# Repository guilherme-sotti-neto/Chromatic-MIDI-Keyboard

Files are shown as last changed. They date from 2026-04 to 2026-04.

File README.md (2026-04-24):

# Chromatic MIDI Button Keyboard 

# About 
This project was made to be open for anyone who wants to make their own Chromatic MIDI Keyboard at home. 
I tried to make it as reliable and fixable as possible.

# Components 
- 1 Arduino Leonardo
- 3 1/4W 220 ohm Resistor
- 3 Buttons 
- 51 Diodes 1N4148 (I recommend them because they are very cheap and overkill for this project)
- 99 MX Hotswap Sockets
- 99 MX 5 Pins Silver Mechanical Switches

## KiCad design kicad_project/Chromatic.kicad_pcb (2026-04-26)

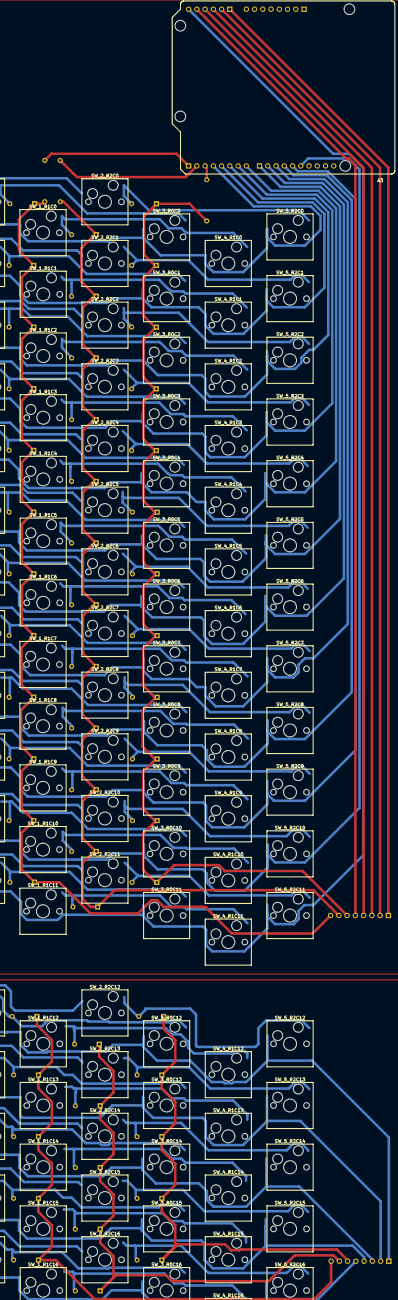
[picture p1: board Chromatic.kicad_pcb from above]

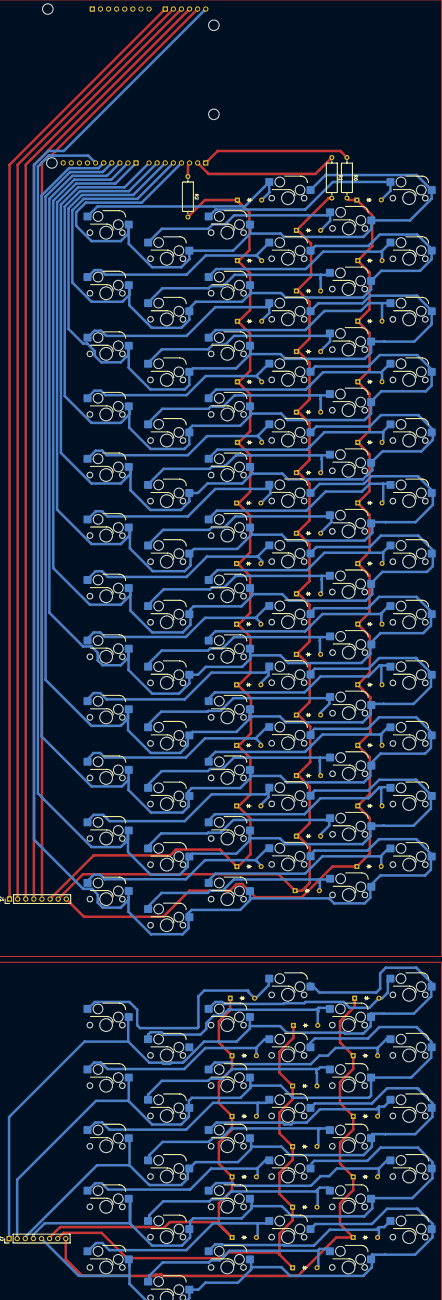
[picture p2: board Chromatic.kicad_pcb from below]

Board: 2 copper layers, 159 parts (56 on the bottom side), 82 nets.

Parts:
A3: Arduino_Leonardo_Shield; ARDUINO_A000066
D_R0C0, D_R0C1, D_R0C2, D_R0C3, D_R0C4, D_R0C5, D_R0C6, D_R0C7, D_R0C8, D_R0C9, D_R0C10, D_R0C11, D_R0C12, D_R0C13, D_R0C14, D_R0C15, D_R0C16, D_R1C0, D_R1C1, D_R1C2, D_R1C3, D_R1C4, D_R1C5, D_R1C6, D_R1C7, D_R1C8, D_R1C9, D_R1C10, D_R1C11, D_R1C12, D_R1C13, D_R1C14, D_R1C15, D_R1C16, D_R2C0, D_R2C1, D_R2C2, D_R2C3, D_R2C4, D_R2C5, D_R2C6, D_R2C7, D_R2C8, D_R2C9, D_R2C10, D_R2C11, D_R2C12, D_R2C13, D_R2C14, D_R2C15, D_R2C16: Diode_DO-35
J1: J1; PinHeader_1x08_P2.54mm_Vertical
J2: J2; PinHeader_1x08_P2.54mm_Vertical
R0, R1, R2: Resistor; R_Axial_DIN0309_L9.0mm_D3.2mm_P12.70mm_Horizontal
SW_0_R0C0, SW_0_R0C1, SW_0_R0C2, SW_0_R0C3, SW_0_R0C4, SW_0_R0C5, SW_0_R0C6, SW_0_R0C7, SW_0_R0C8, SW_0_R0C9, SW_0_R0C10, SW_0_R0C11, SW_0_R0C12, SW_0_R0C13, SW_0_R0C14, SW_0_R0C15, SW_0_R0C16, SW_1_R1C0, SW_1_R1C1, SW_1_R1C2, SW_1_R1C3, SW_1_R1C4, SW_1_R1C5, SW_1_R1C6, SW_1_R1C7, SW_1_R1C8, SW_1_R1C9, SW_1_R1C10, SW_1_R1C11, SW_1_R1C12, SW_1_R1C13, SW_1_R1C14, SW_1_R1C15, SW_1_R1C16, SW_2_R2C0, SW_2_R2C1, SW_2_R2C2, SW_2_R2C3, SW_2_R2C4, SW_2_R2C5, SW_2_R2C6, SW_2_R2C7, SW_2_R2C8, SW_2_R2C9, SW_2_R2C10, SW_2_R2C11, SW_2_R2C12, SW_2_R2C13, SW_2_R2C14, SW_2_R2C15, SW_2_R2C16, SW_3_R0C0, SW_3_R0C1, SW_3_R0C2, SW_3_R0C3, SW_3_R0C4, SW_3_R0C5, SW_3_R0C6, SW_3_R0C7, SW_3_R0C8, SW_3_R0C9, SW_3_R0C10, SW_3_R0C11, SW_3_R0C12, SW_3_R0C13, SW_3_R0C14, SW_3_R0C15, SW_3_R0C16, SW_4_R1C0, SW_4_R1C1, SW_4_R1C2, SW_4_R1C3, SW_4_R1C4, SW_4_R1C5, SW_4_R1C6, SW_4_R1C7, SW_4_R1C8, SW_4_R1C9, SW_4_R1C10, SW_4_R1C11, SW_4_R1C12, SW_4_R1C13, SW_4_R1C14, SW_4_R1C15, SW_4_R1C16, SW_5_R2C0, SW_5_R2C1, SW_5_R2C2, SW_5_R2C3, SW_5_R2C4, SW_5_R2C5, SW_5_R2C6, SW_5_R2C7, SW_5_R2C8, SW_5_R2C9, SW_5_R2C10, SW_5_R2C11, SW_5_R2C12, SW_5_R2C13, SW_5_R2C14, SW_5_R2C15, SW_5_R2C16: Keyswitch; Hotswap_MX_1.00u

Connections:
Column 0: A3.D3 (D3_INT0), SW_0_R0C0.1, SW_1_R1C0.1, SW_2_R2C0.1, SW_3_R0C0.1, SW_4_R1C0.1, SW_5_R2C0.1
Column 1: A3.D4, SW_0_R0C1.1, SW_1_R1C1.1, SW_2_R2C1.1, SW_3_R0C1.1, SW_4_R1C1.1, SW_5_R2C1.1
Column 2: A3.D5, SW_0_R0C2.1, SW_1_R1C2.1, SW_2_R2C2.1, SW_3_R0C2.1, SW_4_R1C2.1, SW_5_R2C2.1
Column 3: A3.D6, SW_0_R0C3.1, SW_1_R1C3.1, SW_2_R2C3.1, SW_3_R0C3.1, SW_4_R1C3.1, SW_5_R2C3.1
Column 4: A3.D7 (D7_INT4), SW_0_R0C4.1, SW_1_R1C4.1, SW_2_R2C4.1, SW_3_R0C4.1, SW_4_R1C4.1, SW_5_R2C4.1
Column 5: A3.D8, SW_0_R0C5.1, SW_1_R1C5.1, SW_2_R2C5.1, SW_3_R0C5.1, SW_4_R1C5.1, SW_5_R2C5.1
Column 6: A3.D9, SW_0_R0C6.1, SW_1_R1C6.1, SW_2_R2C6.1, SW_3_R0C6.1, SW_4_R1C6.1, SW_5_R2C6.1
Column 7: A3.D10, SW_0_R0C7.1, SW_1_R1C7.1, SW_2_R2C7.1, SW_3_R0C7.1, SW_4_R1C7.1, SW_5_R2C7.1
Column 8: A3.D11, SW_0_R0C8.1, SW_1_R1C8.1, SW_2_R2C8.1, SW_3_R0C8.1, SW_4_R1C8.1, SW_5_R2C8.1
Column 9: A3.D12, SW_0_R0C9.1, SW_1_R1C9.1, SW_2_R2C9.1, SW_3_R0C9.1, SW_4_R1C9.1, SW_5_R2C9.1
Column 10: A3.D13, SW_0_R0C10.1, SW_1_R1C10.1, SW_2_R2C10.1, SW_3_R0C10.1, SW_4_R1C10.1, SW_5_R2C10.1
Column 11: A3.A5, SW_0_R0C11.1, SW_1_R1C11.1, SW_2_R2C11.1, SW_3_R0C11.1, SW_4_R1C11.1, SW_5_R2C11.1
Column 12: A3.A0, J1.1
Column 13: A3.A1, J1.2
Column 14: A3.A2, J1.3
Column 15: A3.A3, J1.4
Column 16: A3.A4, J1.5
D_R0C11: D_R0C0.1 (K), D_R0C1.1 (K), D_R0C2.1 (K), D_R0C3.1 (K), D_R0C4.1 (K), D_R0C5.1 (K), D_R0C6.1 (K), D_R0C7.1 (K), D_R0C8.1 (K), D_R0C9.1 (K), D_R0C10.1 (K), D_R0C11.1 (K), J1.8, R0.2
D_R1C11: D_R1C0.1 (K), D_R1C1.1 (K), D_R1C2.1 (K), D_R1C3.1 (K), D_R1C4.1 (K), D_R1C5.1 (K), D_R1C6.1 (K), D_R1C7.1 (K), D_R1C8.1 (K), D_R1C9.1 (K), D_R1C10.1 (K), D_R1C11.1 (K), J1.7, R1.2
D_R2C11: D_R2C0.1 (K), D_R2C1.1 (K), D_R2C2.1 (K), D_R2C3.1 (K), D_R2C4.1 (K), D_R2C5.1 (K), D_R2C6.1 (K), D_R2C7.1 (K), D_R2C8.1 (K), D_R2C9.1 (K), D_R2C10.1 (K), D_R2C11.1 (K), J1.6, R2.2
unnamed: D_R0C0.2 (A), SW_0_R0C0.2, SW_3_R0C0.2
unnamed: D_R0C1.2 (A), SW_0_R0C1.2, SW_3_R0C1.2
unnamed: D_R0C2.2 (A), SW_0_R0C2.2, SW_3_R0C2.2
unnamed: D_R0C3.2 (A), SW_0_R0C3.2, SW_3_R0C3.2
unnamed: D_R0C4.2 (A), SW_0_R0C4.2, SW_3_R0C4.2
unnamed: D_R0C5.2 (A), SW_0_R0C5.2, SW_3_R0C5.2
unnamed: D_R0C6.2 (A), SW_0_R0C6.2, SW_3_R0C6.2
unnamed: D_R0C7.2 (A), SW_0_R0C7.2, SW_3_R0C7.2
unnamed: D_R0C8.2 (A), SW_0_R0C8.2, SW_3_R0C8.2
unnamed: D_R0C9.2 (A), SW_0_R0C9.2, SW_3_R0C9.2
unnamed: D_R0C10.2 (A), SW_0_R0C10.2, SW_3_R0C10.2
unnamed: D_R0C11.2 (A), SW_0_R0C11.2, SW_3_R0C11.2
unnamed: D_R0C12.2 (A), SW_0_R0C12.2, SW_3_R0C12.2
unnamed: D_R0C12.1 (K), D_R0C13.1 (K), D_R0C14.1 (K), D_R0C15.1 (K), D_R0C16.1 (K), J2.8
unnamed: D_R0C13.2 (A), SW_0_R0C13.2, SW_3_R0C13.2
unnamed: D_R0C14.2 (A), SW_0_R0C14.2, SW_3_R0C14.2
unnamed: D_R0C15.2 (A), SW_0_R0C15.2, SW_3_R0C15.2
unnamed: D_R0C16.2 (A), SW_0_R0C16.2, SW_3_R0C16.2
unnamed: D_R1C0.2 (A), SW_1_R1C0.2, SW_4_R1C0.2
unnamed: D_R1C1.2 (A), SW_1_R1C1.2, SW_4_R1C1.2
unnamed: D_R1C2.2 (A), SW_1_R1C2.2, SW_4_R1C2.2
unnamed: D_R1C3.2 (A), SW_1_R1C3.2, SW_4_R1C3.2
unnamed: D_R1C4.2 (A), SW_1_R1C4.2, SW_4_R1C4.2
unnamed: D_R1C5.2 (A), SW_1_R1C5.2, SW_4_R1C5.2
unnamed: D_R1C6.2 (A), SW_1_R1C6.2, SW_4_R1C6.2
unnamed: D_R1C7.2 (A), SW_1_R1C7.2, SW_4_R1C7.2
unnamed: D_R1C8.2 (A), SW_1_R1C8.2, SW_4_R1C8.2
unnamed: D_R1C9.2 (A), SW_1_R1C9.2, SW_4_R1C9.2
unnamed: D_R1C10.2 (A), SW_1_R1C10.2, SW_4_R1C10.2
unnamed: D_R1C11.2 (A), SW_1_R1C11.2, SW_4_R1C11.2
unnamed: D_R1C12.2 (A), SW_1_R1C12.2, SW_4_R1C12.2
unnamed: D_R1C12.1 (K), D_R1C13.1 (K), D_R1C14.1 (K), D_R1C15.1 (K), D_R1C16.1 (K), J2.7
unnamed: D_R1C13.2 (A), SW_1_R1C13.2, SW_4_R1C13.2
unnamed: D_R1C14.2 (A), SW_1_R1C14.2, SW_4_R1C14.2
unnamed: D_R1C15.2 (A), SW_1_R1C15.2, SW_4_R1C15.2
unnamed: D_R1C16.2 (A), SW_1_R1C16.2, SW_4_R1C16.2
unnamed: D_R2C0.2 (A), SW_2_R2C0.2, SW_5_R2C0.2
unnamed: D_R2C1.2 (A), SW_2_R2C1.2, SW_5_R2C1.2
unnamed: D_R2C2.2 (A), SW_2_R2C2.2, SW_5_R2C2.2
unnamed: D_R2C3.2 (A), SW_2_R2C3.2, SW_5_R2C3.2
unnamed: D_R2C4.2 (A), SW_2_R2C4.2, SW_5_R2C4.2
unnamed: D_R2C5.2 (A), SW_2_R2C5.2, SW_5_R2C5.2
unnamed: D_R2C6.2 (A), SW_2_R2C6.2, SW_5_R2C6.2
unnamed: D_R2C7.2 (A), SW_2_R2C7.2, SW_5_R2C7.2
unnamed: D_R2C8.2 (A), SW_2_R2C8.2, SW_5_R2C8.2
unnamed: D_R2C9.2 (A), SW_2_R2C9.2, SW_5_R2C9.2
unnamed: D_R2C10.2 (A), SW_2_R2C10.2, SW_5_R2C10.2
unnamed: D_R2C11.2 (A), SW_2_R2C11.2, SW_5_R2C11.2
unnamed: D_R2C12.2 (A), SW_2_R2C12.2, SW_5_R2C12.2
unnamed: D_R2C12.1 (K), D_R2C13.1 (K), D_R2C14.1 (K), D_R2C15.1 (K), D_R2C16.1 (K), J2.6
unnamed: D_R2C13.2 (A), SW_2_R2C13.2, SW_5_R2C13.2
unnamed: D_R2C14.2 (A), SW_2_R2C14.2, SW_5_R2C14.2
unnamed: D_R2C15.2 (A), SW_2_R2C15.2, SW_5_R2C15.2
unnamed: D_R2C16.2 (A), SW_2_R2C16.2, SW_5_R2C16.2
unnamed: J2.1, SW_0_R0C12.1, SW_1_R1C12.1, SW_2_R2C12.1, SW_3_R0C12.1, SW_4_R1C12.1, SW_5_R2C12.1
unnamed: J2.2, SW_0_R0C13.1, SW_1_R1C13.1, SW_2_R2C13.1, SW_3_R0C13.1, SW_4_R1C13.1, SW_5_R2C13.1
unnamed: J2.3, SW_0_R0C14.1, SW_1_R1C14.1, SW_2_R2C14.1, SW_3_R0C14.1, SW_4_R1C14.1, SW_5_R2C14.1
unnamed: J2.4, SW_0_R0C15.1, SW_1_R1C15.1, SW_2_R2C15.1, SW_3_R0C15.1, SW_4_R1C15.1, SW_5_R2C15.1
unnamed: J2.5, SW_0_R0C16.1, SW_1_R1C16.1, SW_2_R2C16.1, SW_3_R0C16.1, SW_4_R1C16.1, SW_5_R2C16.1
Row 0: A3.D0 (D0/RX), R0.1
Row 1: A3.D1 (D1/TX), R1.1
Row 2: A3.D2 (D2_INT1), R2.1

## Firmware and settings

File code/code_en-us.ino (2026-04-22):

// Includes the native Arduino library for MIDI communication via USB cable.
// The computer will recognize the board as a musical instrument ("Arduino Leonardo:Arduino Leonardo MIDI 1 20:0").
#include "MIDIUSB.h"

// ==========================================
// PHYSICAL MATRIX CONFIGURATIONS
// ==========================================

// Defines the number of rows and columns in the button matrix.
const int NUM_ROWS = 3;  // 3 electrical rows.
const int NUM_COLS = 17; // 17 electrical columns.

// Calculates the maximum number of buttons the matrix supports (3 rows * 17 columns = 51 keys).
const int NUM_KEYS = 51; 

// Indicates which Arduino pins are connected to the Rows.
// Digital pins 0, 1, and 2.
int rowPins[NUM_ROWS] = {0, 1, 2}; 

// Indicates which Arduino pins are connected to the Columns.
// Digital pins 3 to 13, and analog pins A0 to A5 (used as digital).
int colPins[NUM_COLS] = {3, 4, 5, 6, 7, 8, 9, 10, 11, 12, 13, A0, A1, A2, A3, A4, A5};

// ==========================================
// STATE VARIABLES AND ANTI-NOISE FILTER (DEBOUNCE)
// ==========================================

// Array (list) that stores the CURRENT state of each key (true = pressed, false = released).
bool keyState[NUM_KEYS];

// Array that stores the LAST read state of each key to compare if there was a change.
bool lastKeyState[NUM_KEYS];

// Array that records the exact millisecond each key last changed state.
unsigned long lastDebounceTime[NUM_KEYS];

// Time in milliseconds that the Arduino must wait to confirm the button was actually
// pressed or released. This prevents the button's internal metallic "bounce" from generating double notes.
unsigned long debounceDelay = 10; 

// ==========================================
// CONTROL VARIABLES (OCTAVES AND SYSTEMS)
// ==========================================

// Stores the current octave shift. Starts at 0. Can go to +12 (high) or -12 (low).
int octaveShift = 0;      

// Defines which note system is active. 
// false = C-System (Initial default), true = B-System.
bool isBSystem = false;   

// Smart memory: Records the exact note sent to the computer when the key was pressed.
// This prevents a note from getting "stuck" playing forever if you change the octave before releasing it.
int notasAtivas[NUM_KEYS];

// Defines the "position" (mathematical index) of the control buttons within the matrix.
// These buttons are all in Column 0, but on different rows.
const int BTN_OCTAVE_DOWN = 0;  // Octave down button (Row 0 * 17 columns + Column 0)
const int BTN_OCTAVE_UP   = 17; // Octave up button (Row 1 * 17 columns + Column 0)
const int BTN_SYSTEM      = 34; // C/B switch button (Row 2 * 17 columns + Column 0)

// ==========================================
// NOTE MAPS (LOOK-UP TABLES)
// ==========================================

// MAP 1: C-SYSTEM (C-Griff) 
// Defines which default MIDI note each button will play. The number 0 indicates a button without a note (like functions).
int noteMapCSystem[NUM_KEYS] = {
  // Row 0 (The first '0' is the BTN_OCTAVE_DOWN button)
  0, 48, 51, 54, 57, 60, 63, 66, 69, 72, 75, 78, 81, 84, 87, 90, 93,
  // Row 1 (The first '0' is the BTN_OCTAVE_UP button)
  0, 49, 52, 55, 58, 61, 64, 67, 70, 73, 76, 79, 82, 85, 88, 91, 94,
  // Row 2 (The first '0' is the BTN_SYSTEM button)
  0, 50, 53, 56, 59, 62, 65, 68, 71, 74, 77, 80, 83, 86, 89, 92, 95
};

// MAP 2: B-SYSTEM (B-Griff)
// Alternative map for when the system switch button is activated.
int noteMapBSystem[NUM_KEYS] = {
  // Row 0
  0, 47, 50, 53, 56, 59, 62, 65, 68, 71, 74, 77, 80, 83, 86, 89, 92,
  // Row 1
  0, 48, 51, 54, 57, 60, 63, 66, 69, 72, 75, 78, 81, 84, 87, 90, 93,
  // Row 2
  0, 49, 52, 55, 58, 61, 64, 67, 70, 73, 76, 79, 82, 85, 88, 91, 94
};

// ==========================================
// SETUP: INITIAL PREPARATION (Runs only once)
// ==========================================
void setup() {
  // Configures all ROW pins to send power (OUTPUT).
  for (int i = 0; i < NUM_ROWS; i++) {
    pinMode(rowPins[i], OUTPUT);
    digitalWrite(rowPins[i], HIGH); // Keep HIGH (5V) so they remain inactive by default.
  }
  
  // Configures all COLUMN pins to receive power.
  // INPUT_PULLUP enables an internal resistor that keeps columns reading 5V (HIGH) when released.
  for (int i = 0; i < NUM_COLS; i++) {
    pinMode(colPins[i], INPUT_PULLUP);
  }
  
  // Clears all keyboard memories and timers to start fresh.
  for (int i = 0; i < NUM_KEYS; i++) {
    keyState[i] = false;
    lastKeyState[i] = false;
    lastDebounceTime[i] = 0;
    notasAtivas[i] = 0; 
  }
}

// ==========================================
// MAIN LOOP (Runs infinitely and as fast as possible)
// ==========================================
void loop() {
  // Calls the function that scans (radars) the keys.
  scanMatrix();
}

// ==========================================
// MATRIX SCANNING FUNCTION
// ==========================================
void scanMatrix() {
  // Loops through each of the 3 rows, one at a time.
  for (int r = 0; r < NUM_ROWS; r++) {
    
    // Activates the current row by dropping its voltage to 0V (LOW).
    digitalWrite(rowPins[r], LOW); 

    // While the row is active (0V), loops through each of the 17 columns checking for contact.
    for (int c = 0; c < NUM_COLS; c++) {
      
      // Calculates the unique identification number for the key (from 0 to 50).
      int keyIndex = r * NUM_COLS + c;

      // Reads the current column. The "!" symbol inverts the reading. 
      // Since pressing the key generates 0V (false), the "!" turns it into "true" for the code.
      bool reading = !digitalRead(colPins[c]); 

      // If the reading is different from the last recorded state (sign that someone touched or released):
      if (reading != lastKeyState[keyIndex]) {
        // Resets the timer for this specific key by recording the current time (millis).
        lastDebounceTime[keyIndex] = millis();
      }

      // Checks if the signal has stabilized longer than the debounceDelay (10ms).
      if ((millis() - lastDebounceTime[keyIndex]) > debounceDelay) {
        
        // If the stable reading is actually different from the official state saved in memory:
        if (reading != keyState[keyIndex]) {
          // Updates the official memory with the new state.
          keyState[keyIndex] = reading;

          // ==========================================
          // LOGIC FOR WHEN THE KEY IS PRESSED
          // ==========================================
          if (keyState[keyIndex]) {
            
            // --- 1. CHECK IF IT IS ONE OF THE FUNCTION BUTTONS ---
            if (keyIndex == BTN_OCTAVE_DOWN || keyIndex == BTN_OCTAVE_UP || keyIndex == BTN_SYSTEM) {
              
              if (keyIndex == BTN_OCTAVE_DOWN) {
                // Decreases 12 semitones with each press. 
                // Limit of -36 (3 octaves) so the user doesn't "get lost" in silence.
                octaveShift -= 12;
                if (octaveShift < -36) octaveShift = -36; 
              } 
              else if (keyIndex == BTN_OCTAVE_UP) {
                // Increases 12 semitones with each press.
                // Limit of 24 (2 octaves)
                octaveShift += 12;
                if (octaveShift > 24) octaveShift = 24;
              } 
              else if (keyIndex == BTN_SYSTEM) {
                // Toggles between C-System and B-System
                isBSystem = !isBSystem;
              }

              // REAL-TIME MAGIC: Updates the sound of notes already being held at this exact moment.
              for (int i = 0; i < NUM_KEYS; i++) {
                // Skips the function buttons themselves (they don't play sound).
                if (i == BTN_OCTAVE_DOWN || i == BTN_OCTAVE_UP || i == BTN_SYSTEM) continue;

                // If there is an active note recorded in memory for button 'i':
                if (notasAtivas[i] > 0) { 
                  // 1. Sends command to turn off the current old note.
                  noteOff(0, notasAtivas[i], 0);
                  
                  // 2. Checks the map for what the base note of this button should be with the current system.
                  int baseNote = isBSystem ? noteMapBSystem[i] : noteMapCSystem[i];
                  
                  if (baseNote > 0) {
                    // Adds the new tuning/octave and uses 'constrain' to ensure it doesn't exceed 127 or go below 0.
                    int finalNote = constrain(baseNote + octaveShift, 0, 127);
                    
                    // 3. Turns on the note in the new octave instantly and saves it in memory.
                    noteOn(0, finalNote, 127);
                    notasAtivas[i] = finalNote;
                  }
                }
              }
              // Pushes accumulated MIDI messages to USB instantly.
              MidiUSB.flush(); 
            } 
            
            // --- 2. IF IT IS A NORMAL MUSICAL NOTE KEY ---
            else {
              // Finds out what the note is by looking at the correct map based on the chosen system (B or C).
              int baseNote = isBSystem ? noteMapBSystem[keyIndex] : noteMapCSystem[keyIndex];

              // Only plays sound if the map doesn't show '0' for that key.
              if (baseNote > 0) {
                // Calculates the final note including the octave shift, without exceeding the 0 to 127 limit.
                int finalNote = constrain(baseNote + octaveShift, 0, 127); 
                
                // Records which note will be played in memory (so we don't get lost when releasing) and turns it on.
                notasAtivas[keyIndex] = finalNote;
                noteOn(0, finalNote, 127);  
                MidiUSB.flush();           
              }
            }
          } 
          
          // ==========================================
          // LOGIC FOR WHEN THE KEY IS RELEASED
          // ==========================================
          else {
            // If the released button is NOT one of the function buttons:
            if (keyIndex != BTN_OCTAVE_DOWN && keyIndex != BTN_OCTAVE_UP && keyIndex != BTN_SYSTEM) {
              
              // Checks memory to know exactly which MIDI note number had been sent by this key.
              if (notasAtivas[keyIndex] > 0) {
                // Turns off exactly that registered note.
                noteOff(0, notasAtivas[keyIndex], 0);   
                MidiUSB.flush();
                // Clears the memory space for this key.
                notasAtivas[keyIndex] = 0; 
              }
            }
          }
        }
      }
      // Updates the old state with the current raw mechanical reading for the next loop iteration.
      lastKeyState[keyIndex] = reading;
    }
    // Before moving to the next matrix row, turns off the current row by returning it to 5V (HIGH).
    digitalWrite(rowPins[r], HIGH); 
  }
}

// ==========================================
// USB MIDI COMMUNICATION FUNCTIONS
// ==========================================

// Function that builds the data packet required by the MIDI specification to turn a note "On" (Note On).
void noteOn(byte channel, byte pitch, byte velocity) {
  // 0x09 is the USB header for "Note On". 0x90 is the MIDI code for "Note On on channel 0".
  midiEventPacket_t noteOn = {0x09, (byte)(0x90 | channel), pitch, velocity};
  // Sends the packet to the USB buffer.
  MidiUSB.sendMIDI(noteOn);
}

// Function that builds the data packet to turn a note "Off" (Note Off).
void noteOff(byte channel, byte pitch, byte velocity) {
  // 0x08 is the USB header for "Note Off". 0x80 is the MIDI code for "Note Off on channel 0".
  midiEventPacket_t noteOff = {0x08, (byte)(0x80 | channel), pitch, velocity};
  // Sends the packet to the USB buffer.
  MidiUSB.sendMIDI(noteOff);
}

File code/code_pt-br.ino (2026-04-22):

// Inclui a biblioteca nativa do Arduino para comunicação MIDI via cabo USB.
// O computador reconhecerá a placa como um instrumento musical ("Arduino Leonardo:Arduino Leonardo MIDI 1 20:0").
#include "MIDIUSB.h"

// ==========================================
// CONFIGURAÇÕES DA MATRIZ FÍSICA
// ==========================================

// Define a quantidade de linhas e colunas da matriz de botões.
const int NUM_ROWS = 3;  // 3 linhas elétricas.
const int NUM_COLS = 17; // 17 colunas elétricas.

// Calcula o número máximo de botões que a matriz suporta (3 linhas * 17 colunas = 51 teclas).
const int NUM_KEYS = 51; 

// Indica quais pinos do Arduino estão conectados nas Linhas.
// Pinos digitais 0, 1 e 2.
int rowPins[NUM_ROWS] = {0, 1, 2}; 

// Indica quais pinos do Arduino estão conectados nas Colunas.
// Pinos digitais do 3 ao 13, e os pinos analógicos A0 ao A5 (usados como digitais).
int colPins[NUM_COLS] = {3, 4, 5, 6, 7, 8, 9, 10, 11, 12, 13, A0, A1, A2, A3, A4, A5};

// ==========================================
// VARIÁVEIS DE ESTADO E FILTRO ANTI-RUÍDO (DEBOUNCE)
// ==========================================

// Array (lista) que guarda o estado ATUAL de cada tecla (true = pressionada, false = solta).
bool keyState[NUM_KEYS];

// Array que guarda o ÚLTIMO estado lido de cada tecla para comparar se houve mudança.
bool lastKeyState[NUM_KEYS];

// Array que registra o exato milissegundo em que cada tecla mudou de estado pela última vez.
unsigned long lastDebounceTime[NUM_KEYS];

// Tempo em milissegundos que o Arduino deve esperar para confirmar que o botão foi realmente
// apertado ou solto. Isso evita que o "quique" metálico interno do botão gere notas duplas.
unsigned long debounceDelay = 10; 

// ==========================================
// VARIÁVEIS DE CONTROLE (OITAVAS E SISTEMAS)
// ==========================================

// Guarda o deslocamento atual da oitava. Começa em 0. Pode ir para +12 (agudo) ou -12 (grave).
int octaveShift = 0;      

// Define qual sistema de notas está ativo. 
// false = Sistema C (Padrão inicial), true = Sistema B.
bool isBSystem = false;   

// Memória inteligente: Anota a nota exata que foi enviada ao computador quando a tecla foi pressionada.
// Isso impede que uma nota fique "travada" tocando para sempre se você mudar a oitava antes de soltá-la.
int notasAtivas[NUM_KEYS];

// Define a "posição" (índice matemático) dos botões de controle dentro da matriz.
// Estes botões estão todos na Coluna 0, mas em linhas diferentes.
const int BTN_OCTAVE_DOWN = 0;  // Botão de oitava abaixo (Linha 0 * 17 colunas + Coluna 0)
const int BTN_OCTAVE_UP   = 17; // Botão de oitava acima (Linha 1 * 17 colunas + Coluna 0)
const int BTN_SYSTEM      = 34; // Botão de trocar C/B (Linha 2 * 17 colunas + Coluna 0)

// ==========================================
// MAPAS DE NOTAS (LOOK-UP TABLES)
// ==========================================

// MAPA 1: SISTEMA C (C-Griff) 
// Define qual nota MIDI padrão cada botão vai tocar. O número 0 indica botão sem nota (como as funções).
int noteMapCSystem[NUM_KEYS] = {
  // Linha 0 (O primeiro '0' é o botão BTN_OCTAVE_DOWN)
  0, 48, 51, 54, 57, 60, 63, 66, 69, 72, 75, 78, 81, 84, 87, 90, 93,
  // Linha 1 (O primeiro '0' é o botão BTN_OCTAVE_UP)
  0, 49, 52, 55, 58, 61, 64, 67, 70, 73, 76, 79, 82, 85, 88, 91, 94,
  // Linha 2 (O primeiro '0' é o botão BTN_SYSTEM)
  0, 50, 53, 56, 59, 62, 65, 68, 71, 74, 77, 80, 83, 86, 89, 92, 95
};

// MAPA 2: SISTEMA B (B-Griff)
// Mapa alternativo para quando o botão de trocar de sistema for ativado.
int noteMapBSystem[NUM_KEYS] = {
  // Linha 0
  0, 47, 50, 53, 56, 59, 62, 65, 68, 71, 74, 77, 80, 83, 86, 89, 92,
  // Linha 1
  0, 48, 51, 54, 57, 60, 63, 66, 69, 72, 75, 78, 81, 84, 87, 90, 93,
  // Linha 2
  0, 49, 52, 55, 58, 61, 64, 67, 70, 73, 76, 79, 82, 85, 88, 91, 94
};

// ==========================================
// SETUP: PREPARAÇÃO INICIAL (Roda apenas uma vez)
// ==========================================
void setup() {
  // Configura todos os pinos das LINHAS para enviar energia (OUTPUT).
  for (int i = 0; i < NUM_ROWS; i++) {
    pinMode(rowPins[i], OUTPUT);
    digitalWrite(rowPins[i], HIGH); // Deixa em HIGH (5V) para que fiquem inativos por padrão.
  }
  
  // Configura todos os pinos das COLUNAS para receber energia.
  // O INPUT_PULLUP liga um resistor interno que mantém as colunas lendo 5V (HIGH) quando soltas.
  for (int i = 0; i < NUM_COLS; i++) {
    pinMode(colPins[i], INPUT_PULLUP);
  }
  
  // Limpa todas as memórias e cronômetros do teclado para iniciar zerado.
  for (int i = 0; i < NUM_KEYS; i++) {
    keyState[i] = false;
    lastKeyState[i] = false;
    lastDebounceTime[i] = 0;
    notasAtivas[i] = 0; 
  }
}

// ==========================================
// LOOP PRINCIPAL (Roda infinitamente e o mais rápido possível)
// ==========================================
void loop() {
  // Chama a função que faz a varredura (radar) das teclas.
  scanMatrix();
}
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

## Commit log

2026-04-19 inicio das coisas
    inicio do esquema e codigo
    [Chromatic.kicad_pcb, Chromatic.kicad_sch]
2026-04-21 teste, pcb, esquema
    codigo de teste criado;
    atualizaçoes no pcb e esquema.
    [Chromatic.kicad_pcb, Chromatic.kicad_sch]
2026-04-21 octave adjust
    [Chromatic.kicad_pcb]
2026-04-26 LAYOUT OK
    [Chromatic.kicad_pcb]
